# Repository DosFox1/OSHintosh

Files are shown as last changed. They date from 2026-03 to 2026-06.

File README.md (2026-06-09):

# OSHintosh
OSHintosh - an open source hardware Diskless 68000 Macintosh with a Bootable ROM Disk, using absolutely no hardware from Apple!

OSHintosh Complete

OSHintosh operating

OSHintosh running

# DISCLAIMER
The initial VDEV1 board required a large amount of bodges to become operational, these are as follows:

1) Added missing track between pin 1 of the 74ls161s, and pin 8 of the 74ls04 inverter
2) 1x missing 47R resistor TSEN2 from pin 11 of the TSG and ASG to ground
3) 4x missing 2k2 pull up resistors on address lines A9, A10, A11, A12
4) 2x missing 3k3 pull up resistors on !AS and !VIAIRQ
5) pin 4 of IC43 should be connected to -12v, not GND
6) pin 12 of IC18 should be connected to track VA11, not track VA12
7) pin 8 of IC43 should be connected to +12v, not 5V
8) errors on silkscreen for R68, R69, R70 and R71 (Schematic and BOM correct, silkscreen incorrect)
9) errors on silkscreen for R40 and R43 (Schematic and BOM correct, silkscreen incorrect)

VDEV2 has been completed and uploaded. This version should fix all problems with the VDEV1 board, but has not been tested. 

OSHintosh VDEV1 Bodges

# Renders of the VDEV2 Board

OSHintosh Top High Res
OSHintosh Bottom High Res

# So, what is it?
In a nutshell, the OSHintosh is a Macintosh 512Ke Logic Board - but with the exception that it boots from a disk baked into the ROM, power it provided by an ATX power supply, there is an integrated Pico Scan Converter, as well as a SCHWIM to replace the IWM.
The ROM disk is based off the excellent original (ROMinator)[https://www.bigmessowires.com/mac-rom-inator/], and the OSHintosh also has the option to access further files from a LocalTalk server. 

There is no SCSI, No Floppy Drive or any other Mass Storage - it is effectively a Diskless Workstation!
It could be considered to be the spiritual sucessor to the Macintosh XO (also known as the Macintosh Classic!)

The board has also been designed in only two layers, which reduces the cost of the board even further.
JLCPCB suggest that five boards will cost £30 - so only £6 per board. Your mileage may vary. 
41256 RAM was chosen, as it at least avoids the issue of trying to source 30 pin RAM sockets - which are weirdly expensive now. 
It also makes the entire thing a DIP THT Macintosh!

This makes it the first Macintosh designed on a two layer PCB since the "SCC Word Wide" Prototype from 1982!
The board is more or less ATX shaped, but I didn't place the mounting holes to be ATX compliant. Sorry!

This is intended to fit somewhere between the excellent ITX Plus by Max1zzz and the equally excellent PicoMac by evansm7.  
I say this as the RAM is limited to 512K and there is no mass storage, but it does have "real" Localtalk ports to communicate with an AppleTalk network - as well as sound!

# Programmer Requirements:
A Ti866 or similar programmer is recommended. 
In total there are nine programmable ICs that need to be programmed. These are:
1) 6 x 16V8 GALs
2) 2 x 39F040 EEPROMs
3) 1 x ATTINY85 (RTC)

# Hard (ish) to Source Components:
Please Note that the following ICs may be difficult to source:
1) 15.6672mhz oscillator (ebay may have some, if not, custom oscillators can be ordered)
2) Zilog Z8530 SCC
3) 6522 VIA (Demik has noted that the W65C22N6TPG should be a suitable VIA, that's still being made!)
4) 41256 DRAM (x16!)

Please also note this assumes that you have access to either original Macintosh Peripherals, or will add your own adapters!
The OSHintosh uses the original quadrature 9 pin mouse, as well as the original RJ Keyboard. 

# GAL JED Files:
The GALs were sourced from the PLD archive:
https://wiki.pldarchive.co.uk/index.php?title=Macintosh_128k/512k/Plus
For completeness, they have been included here under "OSHintosh GALs". 

Programming can be completed under minipro with:
```
minipro -p GAL16V8* -w (GAL)16V8.jed
```

Equations will be uploaded... eventually.

# Programming the Attiny85 with Minipro 

The ATTINY85 RTC firmware as developed by pgreenland (https://github.com/pgreenland/attinyrtc) can be programmed with a Ti866 under Minipro:
The following erases the ATTINY85:
```
minipro -p ATTINY85 -E
```
Then, the fuses as defined by the file attiny_RTC.fuses is flashed
```
minipro -p ATTINY85 -c config -w attiny_RTC.fuses -e
```
Finally, the firmware is flashed to the ATTINY:
```
minipro -p ATTINY85 -e -c code -f ihex -w ATtinyRTC.hex
```

# Producing new Rominator Disks with a Minipro 

Normally, the ROMinator is designed to be programmed using the BMOW flasher tool onboard the macintosh.
However, this assumes we already have a method of adding mass storage to the Macintosh, which the OSHintosh lacks. 
(https://www.bigmessowires.com/mac-rom-inator/)

As it transpires, the ROMinator just literally tacks an 885K .DSK image onto the end of the modified ROM.
Therefore, the best way to produce a modded ROM is to use mini vmac (or any other suitable emulator!) to modify a copy of the dsk image 
"rominator-disk.dsk" with the desired files and programs
. I would suggest just deleting any unwanted files rather than erasing the disk, as I feel it might break something if it is erased. 
Once content with the resulting disk, the "raw" rominator binary (basically the rominator rom without the disk image) and the new disk should be concatenated together. 

On a Unix machine, this can be done with cat:
```
cat ROMINATOR_RAW.bin oshintosh_disk.dsk > OSHINTOSH_COMBINED.bin
```

In this example, I am using my oshintosh_disk.dsk to create OSHINTOSH_COMBINED.bin.

The next step is to split the comnbined .bin file into two high and low images for the OSHintosh. 
To generate the HIGH ROM:
```
srec_cat -o HIGH.bin -binary OSHINTOSH_COMBINED.bin -binary -split 2 0
```

To generate the LOW ROM:
```
srec_cat -o LOW.bin -binary OSHINTOSH_COMBINED.bin -binary -split 2 1
```

Finally, the two resulting images can then be flashed to the EEPROMs:
```
minipro -p SST39SF040 -w OSHINTOSH_LOW.bin 
```
```
minipro -p SST39SF040 -w OSHINTOSH_HIGH.bin
```

If successful, the OSHintosh should "ping" rather than the usual chime, and when "R" is pressed, the OSHintosh should boot from the ROM.

# Note regarding AppleShare, Chooser and the OSHintosh Serial Ports

If you are wishing to use appleshare to run programs on the OSHintosh, it is best that you use the OSHintosh Disk.dsk files as a starting point. 

This is as the variant of chooser on this startup disk has been recovered from the Macintosh Classic ROM Disk.

Normally, Chooser does not start up on a locked disk. However, the variant of chooser that is found on the Macintosh Classic ROM Disk does work on locked startup disks!

As such, start with the system file as found in OSHintosh Disk.dsk, or OSHintosh Disk 6.0.8.dsk

Additionally, the printer port/Appleshare is connector CN3 (middle connector), and the Modem connector is CN2 (leftmost connector). 

AppleShare on the OSHintosh

# Acknowledgements:
Many thanks to:
AlextheCat,
Bitsavers,
Bolle,
Daniel Kottke,
Demik,
GuruThree, 
HKZ,
Mattmos,
Max1zzz,
Pgreenland,
The PLD Archive,

and many others!

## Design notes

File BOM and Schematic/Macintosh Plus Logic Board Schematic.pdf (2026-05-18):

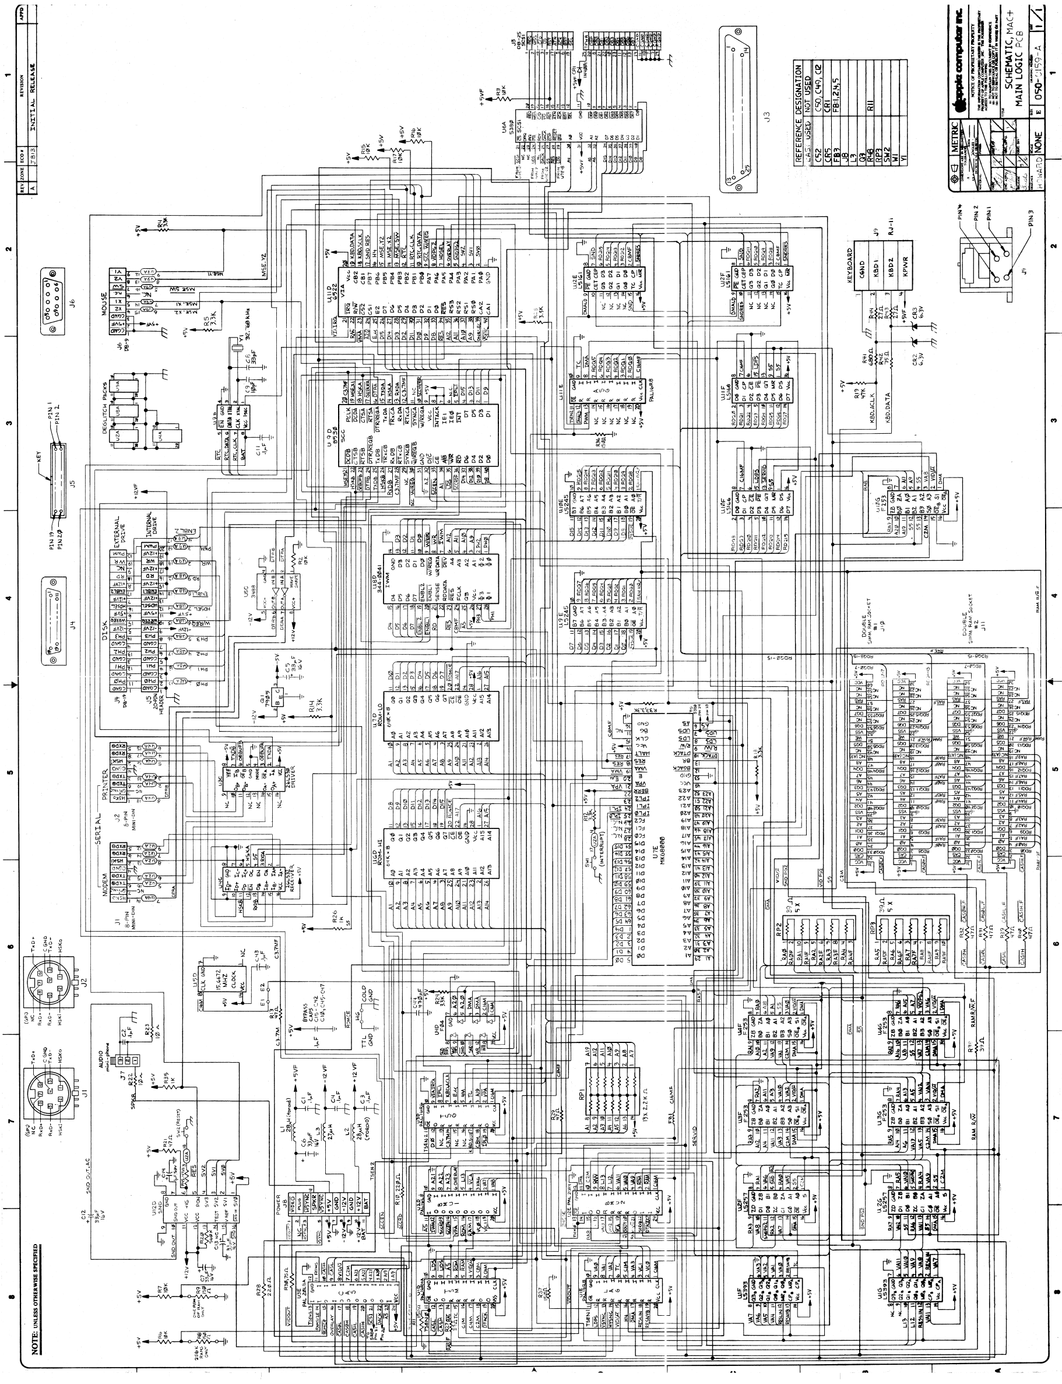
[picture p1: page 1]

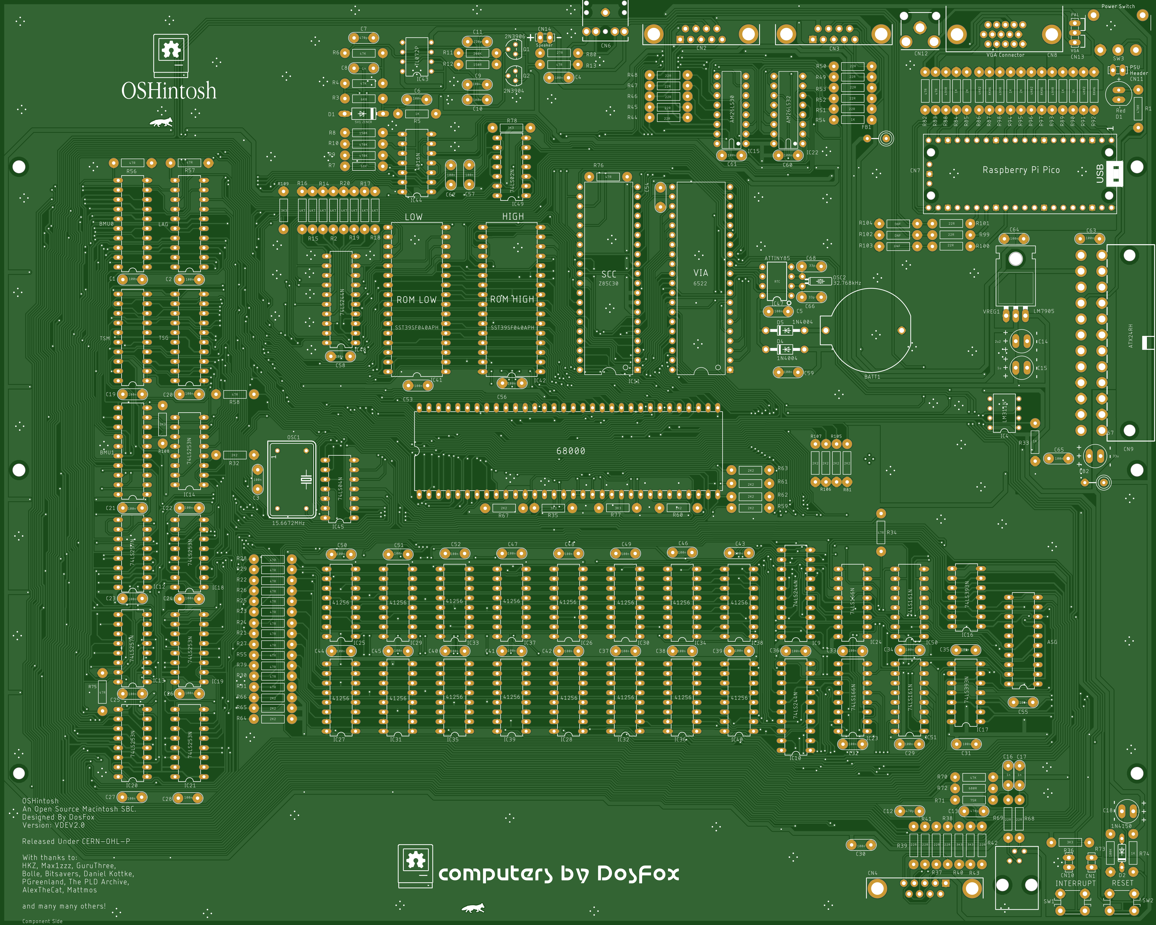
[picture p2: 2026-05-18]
Renders/OSHintosh Top High Res.png

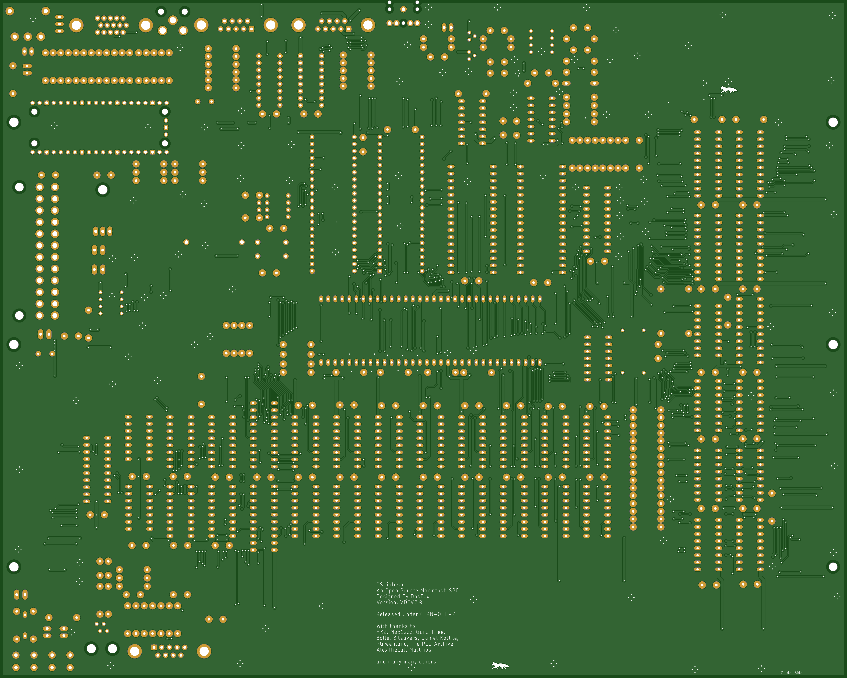
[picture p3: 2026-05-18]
Renders/OSHintosh Bottom High Res.png

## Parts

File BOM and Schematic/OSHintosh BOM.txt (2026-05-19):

Partlist

Exported from OSHintosh v23.sch at 20/Mar/26 10:36

EAGLE Version 9.7.0 Copyright (c) 1988-2026 Autodesk, Inc.

Assembly variant: 

Part     Value                Device                       Package                      Library                 Sheet

BATT1                         BATTERY-20MM_PTH             BATTCOM_20MM_PTH             SparkFun-Batteries      1
C1       100n 50V             100N_TH_CAP                  CAP_5.08MM_PITCH             Capacitors TH           1
C2       100n 50V             100N_TH_CAP                  CAP_5.08MM_PITCH             Capacitors TH           1
C3       100n 50V             100N_TH_CAP                  CAP_5.08MM_PITCH             Capacitors TH           1
C4       100n 50V             100N_TH_CAP                  CAP_5.08MM_PITCH             Capacitors TH           1
C5       100n 50V             100N_TH_CAP                  CAP_5.08MM_PITCH             Capacitors TH           1
C6       100n 50V             100N_TH_CAP                  CAP_5.08MM_PITCH             Capacitors TH           1
C7       470p 50V             470P_TH_CAP                  CAP_5.08MM_PITCH             Capacitors TH           1
C8       1n 50V               1N_TH_CAP                    CAP_5.08MM_PITCH             Capacitors TH           1
C9       100n 50V             100N_TH_CAP                  CAP_5.08MM_PITCH             Capacitors TH           1
C10      100n 50V             100N_TH_CAP                  CAP_5.08MM_PITCH             Capacitors TH           1
C11      220p 50V             220P_TH_CAP                  CAP_5.08MM_PITCH             Capacitors TH           1
C12      470p 50V             470P_TH_CAP                  CAP_5.08MM_PITCH             Capacitors TH           1
C13      470p 50V             470P_TH_CAP                  CAP_5.08MM_PITCH             Capacitors TH           1
C14      2u2 50V              2U2_TH_ELEC_CAPVERTICAL      CAP_ELECTROLYTIC             Capacitors TH           1
C15      1u 50V               1U_TH_ELEC_CAPVERTICAL       CAP_ELECTROLYTIC             Capacitors TH           1
C16      1n 50V               1N_TH_CAP                    CAP_5.08MM_PITCH             Capacitors TH           1
C17      1n 50V               1N_TH_CAP                    CAP_5.08MM_PITCH             Capacitors TH           1
C18      4u7 50V              4U7_TH_ELEC_CAPVERTICAL      CAP_ELECTROLYTIC             Capacitors TH           1
C19      100n 50V             100N_TH_CAP                  CAP_5.08MM_PITCH             Capacitors TH           1
C20      100n 50V             100N_TH_CAP                  CAP_5.08MM_PITCH             Capacitors TH           1
C21      100n 50V             100N_TH_CAP                  CAP_5.08MM_PITCH             Capacitors TH           1
C22      100n 50V             100N_TH_CAP                  CAP_5.08MM_PITCH             Capacitors TH           1
C23      100n 50V             100N_TH_CAP                  CAP_5.08MM_PITCH             Capacitors TH           1
C24      100n 50V             100N_TH_CAP                  CAP_5.08MM_PITCH             Capacitors TH           1
C25      100n 50V             100N_TH_CAP                  CAP_5.08MM_PITCH             Capacitors TH           1
C26      100n 50V             100N_TH_CAP                  CAP_5.08MM_PITCH             Capacitors TH           1
C27      100n 50V             100N_TH_CAP                  CAP_5.08MM_PITCH             Capacitors TH           1
C28      100n 50V             100N_TH_CAP                  CAP_5.08MM_PITCH             Capacitors TH           1
C29      100n 50V             100N_TH_CAP                  CAP_5.08MM_PITCH             Capacitors TH           1
C30      100n 50V             100N_TH_CAP                  CAP_5.08MM_PITCH             Capacitors TH           1
C31      100n 50V             100N_TH_CAP                  CAP_5.08MM_PITCH             Capacitors TH           1
C32      100n 50V             100N_TH_CAP                  CAP_5.08MM_PITCH             Capacitors TH           1
C33      100n 50V             100N_TH_CAP                  CAP_5.08MM_PITCH             Capacitors TH           1
C34      100n 50V             100N_TH_CAP                  CAP_5.08MM_PITCH             Capacitors TH           1
C35      100n 50V             100N_TH_CAP                  CAP_5.08MM_PITCH             Capacitors TH           1
C36      100n 50V             100N_TH_CAP                  CAP_5.08MM_PITCH             Capacitors TH           1
C37      100n 50V             100N_TH_CAP                  CAP_5.08MM_PITCH             Capacitors TH           1
C38      100n 50V             100N_TH_CAP                  CAP_5.08MM_PITCH             Capacitors TH           1
C39      100n 50V             100N_TH_CAP                  CAP_5.08MM_PITCH             Capacitors TH           1
C40      100n 50V             100N_TH_CAP                  CAP_5.08MM_PITCH             Capacitors TH           1
C41      100n 50V             100N_TH_CAP                  CAP_5.08MM_PITCH             Capacitors TH           1
C42      100n 50V             100N_TH_CAP                  CAP_5.08MM_PITCH             Capacitors TH           1
C43      100n 50V             100N_TH_CAP                  CAP_5.08MM_PITCH             Capacitors TH           1
C44      100n 50V             100N_TH_CAP                  CAP_5.08MM_PITCH             Capacitors TH           1
C45      100n 50V             100N_TH_CAP                  CAP_5.08MM_PITCH             Capacitors TH           1
C46      100n 50V             100N_TH_CAP                  CAP_5.08MM_PITCH             Capacitors TH           1
C47      100n 50V             100N_TH_CAP                  CAP_5.08MM_PITCH             Capacitors TH           1
C48      100n 50V             100N_TH_CAP                  CAP_5.08MM_PITCH             Capacitors TH           1
C49      100n 50V             100N_TH_CAP                  CAP_5.08MM_PITCH             Capacitors TH           1
C50      100n 50V             100N_TH_CAP                  CAP_5.08MM_PITCH             Capacitors TH           1
C51      100n 50V             100N_TH_CAP                  CAP_5.08MM_PITCH             Capacitors TH           1
C52      100n 50V             100N_TH_CAP                  CAP_5.08MM_PITCH             Capacitors TH           1
C53      100n 50V             100N_TH_CAP                  CAP_5.08MM_PITCH             Capacitors TH           1
C54      100n 50V             100N_TH_CAP                  CAP_5.08MM_PITCH             Capacitors TH           1
C55      100n 50V             100N_TH_CAP                  CAP_5.08MM_PITCH             Capacitors TH           1
C56      100n 50V             100N_TH_CAP                  CAP_5.08MM_PITCH             Capacitors TH           1
C57      100n 50V             100N_TH_CAP                  CAP_5.08MM_PITCH             Capacitors TH           1
C58      100n 50V             100N_TH_CAP                  CAP_5.08MM_PITCH             Capacitors TH           1
C59      100n 50V             100N_TH_CAP                  CAP_5.08MM_PITCH             Capacitors TH           1
C60      100n 50V             100N_TH_CAP                  CAP_5.08MM_PITCH             Capacitors TH           1
C61      100n 50V             100N_TH_CAP                  CAP_5.08MM_PITCH             Capacitors TH           1
C62      100n 50V             100N_TH_CAP                  CAP_5.08MM_PITCH             Capacitors TH           1
C63      100n 50V             100N_TH_CAP                  CAP_5.08MM_PITCH             Capacitors TH           1
C64      100n 50V             100N_TH_CAP                  CAP_5.08MM_PITCH             Capacitors TH           1
C65      100n 50V             100N_TH_CAP                  CAP_5.08MM_PITCH             Capacitors TH           1
C66      33p                  33P_TH_CAP                   CAP_5.08MM_PITCH             Capacitors TH           1
C67      33u 16V              33U_TH_ELEC_CAPVERTICAL      CAP_ELECTROLYTIC             Capacitors TH           1
C68      33p                  33P_TH_CAP                   CAP_5.08MM_PITCH             Capacitors TH           1
CN1      2way                 PIN_HEADER_2W_VERT_TH        2W_2.54MM_PITCH_VERT_TH      Connectors              1
CN2                           DB9FEMALE                    DB9                          SparkFun-Connectors     1
CN3                           DB9FEMALE                    DB9                          SparkFun-Connectors     1
CN4                           DB9FEMALE                    DB9                          SparkFun-Connectors     1
CN5      XRJK-S-01-6-4-0-9M2  XRJK-S-01-6-4-0-9M2          XRJK-S-01-6-4-0-9M2          con-xmultiple           1
CN6      AUDIO_JACK_3.5MM_PTH AUDIO_JACK_3.5MM_PTH         AUDIO-JACK                   SparkFun-Connectors     1
CN7      V06-1x20-SV-GF-1     PICO_BOARD                   PICO_SOCKET                  uProcessor              1
CN8      DB15                 DB15                         DB15                         SparkFun-Retired        1
CN9      ATX24RH              ATX24RH                      ATX24_RIGHT_ANGLE            SparkFun-Connectors     1
CN10     2way                 PIN_HEADER_2W_VERT_TH        2W_2.54MM_PITCH_VERT_TH      Connectors              1
CN11     2way                 PIN_HEADER_2W_VERT_TH        2W_2.54MM_PITCH_VERT_TH      Connectors              1
CN12     RCA                  RCA                          RCA                          SparkFun-Connectors     1
CN13     V06-1x3-SV-GF-1      PIN_HEADER_3W_VERT_FEMALE_TH 3W_2.54MM_PITCH_VERT_TH      Connectors              1
CN14     2way                 PIN_HEADER_2W_VERT_TH        2W_2.54MM_PITCH_VERT_TH      Connectors              1
D1       5V1 Zener            ZENER-DIODEF126-10           F126Z10                      diode                   1
D2       1N4150               1N4148DO35-7                 DO35-7                       diode                   1
D3       Red                  5MM_LED_RED                  5MM_TH_VERT_STANDARD         Optoelectronics         1
D4       1N4004               1N4004                       DO41-10                      adafruit                1
D5       1N4004               1N4004                       DO41-10                      adafruit                1
FB1      FB                   FB                           FB                           adafruit                1
FB2      FB                   FB                           FB                           adafruit                1
IC1      68000                MC68000P                     DIL64                        micro-mc68000           1
IC2      TSM                  16V8                         DIL20                        pal                     1
IC3      LAG                  16V8                         DIL20                        pal                     1
IC4      LM311N               LM311N                       DIL08                        linear                  1
IC5      TSG                  16V8                         DIL20                        pal                     1
IC6      ASG                  16V8                         DIL20                        pal                     1
IC7      BMU0                 16V8                         DIL20                        pal                     1
IC8      BMU1                 16L8                         DIL20                        pal                     1
IC9      74LS244N             74LS244N                     DIL20                        74xx-eu                 1
IC10     74LS244N             74LS244N                     DIL20                        74xx-eu                 1
IC11     Z85C30               Z85C30                       DIP40                        ICs                     1
IC12     74LS257N             74LS257N                     DIL16                        74xx-eu                 1
IC13     74LS257N             74LS257N                     DIL16                        74xx-eu                 1
IC14     74LS253N             74LS253N                     DIL16                        74xx-eu                 1
IC15     AM26LS30             AM26LS30                     DIP16                        ICs                     1
IC16     74LS393N             74LS393N                     DIL14                        74xx-eu                 1
IC17     74LS393N             74LS393N                     DIL14                        74xx-eu                 1
IC18     74LS253N             74LS253N                     DIL16                        74xx-eu                 1
IC19     74LS253N             74LS253N                     DIL16                        74xx-eu                 1
IC20     74LS253N             74LS253N                     DIL16                        74xx-eu                 1
IC21     74LS253N             74LS253N                     DIL16                        74xx-eu                 1
IC22     AM26LS32             AM26LS32                     DIP16                        ICs                     1
IC23     74LS166N             74LS166N                     DIL16                        74xx-eu                 1
IC24     74LS166N             74LS166N                     DIL16                        74xx-eu                 1
IC25     RAM                  41256C/D                     DIL16                        memory-nec              1
IC26     RAM                  41256C/D                     DIL16                        memory-nec              1
IC27     RAM                  41256C/D                     DIL16                        memory-nec              1
IC28     RAM                  41256C/D                     DIL16                        memory-nec              1
IC29     RAM                  41256C/D                     DIL16                        memory-nec              1
IC30     RAM                  41256C/D                     DIL16                        memory-nec              1
IC31     RAM                  41256C/D                     DIL16                        memory-nec              1
IC32     RAM                  41256C/D                     DIL16                        memory-nec              1
IC33     RAM                  41256C/D                     DIL16                        memory-nec              1
IC34     RAM                  41256C/D                     DIL16                        memory-nec              1
IC35     RAM                  41256C/D                     DIL16                        memory-nec              1
IC36     RAM                  41256C/D                     DIL16                        memory-nec              1
IC37     RAM                  41256C/D                     DIL16                        memory-nec              1
IC38     RAM                  41256C/D                     DIL16                        memory-nec              1
IC39     RAM                  41256C/D                     DIL16                        memory-nec              1
IC40     RAM                  41256C/D                     DIL16                        memory-nec              1
IC41     SST39SF040APH        SST39SF040APH                DIL32                        memory-sst              1
IC42     SST39SF040APH        SST39SF040APH                DIL32                        memory-sst              1
IC43     TL072P               TL072P                       DIL08                        linear                  1
IC44     4016N                4016N                        DIL14                        40xx                    1
IC45     74LS04N              74LS04N                      DIL14                        74xx-eu                 1
IC46     6522                 G65SC22P                     DIP-40                       65XXX                   1
IC47     ATTINY85             ATTINY45TINY85-20-DIP        DIP08_MCU                    SparkFun-Retired        1
IC48     74LS244N             74LS244N                     DIL20                        74xx-eu                 1
IC49     74LS02N              74LS02N                      DIL14                        74xx-us                 1
IC50     74LS161N             74LS161N                     DIL16                        74ttl-din               1
IC51     74LS161N             74LS161N                     DIL16                        74ttl-din               1
OSC1     15.6672MHz           XO-14                        DIL14S                       crystal                 1
OSC2     32.768kHz            CRYSTAL-32.768KHZPTH-2X6     CRYSTAL-PTH-2X6-CYL          SparkFun-Clocks         1
Q1       2N3906               2N3906                       TO92                         transistor-pnp          1
Q2       2N3904               2N3904                       TO92D                        transistor-small-signal 1
R1       470R                 470R_TH_RESISTOR             RESISTORTHRUHOLE             Resistors TH            1
R2       4k7                  4K7_TH_RESISTOR              RESISTORTHRUHOLE             Resistors TH            1
R3       6k8                  6K8_TH_RESISTOR              RESISTORTHRUHOLE             Resistors TH            1
R4       47k                  47K_TH_RESISTOR              RESISTORTHRUHOLE             Resistors TH            1
R5       1k                   1K_TH_RESISTOR               RESISTORTHRUHOLE             Resistors TH            1
R6       47k                  47K_TH_RESISTOR              RESISTORTHRUHOLE             Resistors TH            1
R7       68k                  68K_TH_RESISTOR              RESISTORTHRUHOLE             Resistors TH            1
R8       150k                 150K_TH_RESISTOR             RESISTORTHRUHOLE             Resistors TH            1
R9       470k                 470K_TH_RESISTOR             RESISTORTHRUHOLE             Resistors TH            1
R10      470k                 470K_TH_RESISTOR             RESISTORTHRUHOLE             Resistors TH            1
R11      200k                 100K_TH_RESISTOR             RESISTORTHRUHOLE             Resistors TH            1
R12      150R                 150R_TH_RESISTOR             RESISTORTHRUHOLE             Resistors TH            1
R13      27R                  27R_TH_RESISTOR              RESISTORTHRUHOLE             Resistors TH            1
R14      4k7                  4K7_TH_RESISTOR              RESISTORTHRUHOLE             Resistors TH            1
R15      4k7                  4K7_TH_RESISTOR              RESISTORTHRUHOLE             Resistors TH            1
R16      4k7                  4K7_TH_RESISTOR              RESISTORTHRUHOLE             Resistors TH            1
R17      4k7                  4K7_TH_RESISTOR              RESISTORTHRUHOLE             Resistors TH            1
R18      4k7                  4K7_TH_RESISTOR              RESISTORTHRUHOLE             Resistors TH            1
R19      4k7                  4K7_TH_RESISTOR              RESISTORTHRUHOLE             Resistors TH            1
R20      4k7                  4K7_TH_RESISTOR              RESISTORTHRUHOLE             Resistors TH            1
R21      47R                  47R_TH_RESISTOR              RESISTORTHRUHOLE             Resistors TH            1
R22      47R                  47R_TH_RESISTOR              RESISTORTHRUHOLE             Resistors TH            1
R23      47R                  47R_TH_RESISTOR              RESISTORTHRUHOLE             Resistors TH            1
R24      47R                  47R_TH_RESISTOR              RESISTORTHRUHOLE             Resistors TH            1
R25      47R                  47R_TH_RESISTOR              RESISTORTHRUHOLE             Resistors TH            1
R26      47R                  47R_TH_RESISTOR              RESISTORTHRUHOLE             Resistors TH            1
R27      47R                  47R_TH_RESISTOR              RESISTORTHRUHOLE             Resistors TH            1
R28      47R                  47R_TH_RESISTOR              RESISTORTHRUHOLE             Resistors TH            1
R29      47R                  47R_TH_RESISTOR              RESISTORTHRUHOLE             Resistors TH            1
R30      47R                  47R_TH_RESISTOR              RESISTORTHRUHOLE             Resistors TH            1
R31      47R                  47R_TH_RESISTOR              RESISTORTHRUHOLE             Resistors TH            1
R32      2k2                  2K2_TH_RESISTOR              RESISTORTHRUHOLE             Resistors TH            1
R33      1k                   1K_TH_RESISTOR               RESISTORTHRUHOLE             Resistors TH            1
R34      47R                  47R_TH_RESISTOR              RESISTORTHRUHOLE             Resistors TH            1
R35      3k3                  3K3_TH_RESISTOR              RESISTORTHRUHOLE             Resistors TH            1
R36      3k3                  3K3_TH_RESISTOR              RESISTORTHRUHOLE             Resistors TH            1
R37      22R                  22R_TH_RESISTOR              RESISTORTHRUHOLE             Resistors TH            1
R38      22R                  22R_TH_RESISTOR              RESISTORTHRUHOLE             Resistors TH            1
R39      22R                  22R_TH_RESISTOR              RESISTORTHRUHOLE             Resistors TH            1
R40      3k3                  3K3_TH_RESISTOR              RESISTORTHRUHOLE             Resistors TH            1
R41      22R                  22R_TH_RESISTOR              RESISTORTHRUHOLE             Resistors TH            1
R42      22R                  22R_TH_RESISTOR              RESISTORTHRUHOLE             Resistors TH            1
R43      3k3                  3K3_TH_RESISTOR              RESISTORTHRUHOLE             Resistors TH            1
R44      22R                  22R_TH_RESISTOR              RESISTORTHRUHOLE             Resistors TH            1
R45      22R                  22R_TH_RESISTOR              RESISTORTHRUHOLE             Resistors TH            1
R46      22R                  22R_TH_RESISTOR              RESISTORTHRUHOLE             Resistors TH            1
R47      22R                  22R_TH_RESISTOR              RESISTORTHRUHOLE             Resistors TH            1
R48      22R                  22R_TH_RESISTOR              RESISTORTHRUHOLE             Resistors TH            1
R49      22R                  22R_TH_RESISTOR              RESISTORTHRUHOLE             Resistors TH            1
R50      22R                  22R_TH_RESISTOR              RESISTORTHRUHOLE             Resistors TH            1
R51      22R                  22R_TH_RESISTOR              RESISTORTHRUHOLE             Resistors TH            1
R52      22R                  22R_TH_RESISTOR              RESISTORTHRUHOLE             Resistors TH            1
R53      22R                  22R_TH_RESISTOR              RESISTORTHRUHOLE             Resistors TH            1
R54      1k                   1K_TH_RESISTOR               RESISTORTHRUHOLE             Resistors TH            1
R55      47R                  47R_TH_RESISTOR              RESISTORTHRUHOLE             Resistors TH            1
R56      47R                  47R_TH_RESISTOR              RESISTORTHRUHOLE             Resistors TH            1
R57      47R                  47R_TH_RESISTOR              RESISTORTHRUHOLE             Resistors TH            1
R58      47R                  47R_TH_RESISTOR              RESISTORTHRUHOLE             Resistors TH            1
R59      2k2                  2K2_TH_RESISTOR              RESISTORTHRUHOLE             Resistors TH            1
R60      2k2                  2K2_TH_RESISTOR              RESISTORTHRUHOLE             Resistors TH            1
R61      2k2                  2K2_TH_RESISTOR              RESISTORTHRUHOLE             Resistors TH            1
R62      2k2                  2K2_TH_RESISTOR              RESISTORTHRUHOLE             Resistors TH            1
R63      2k2                  2K2_TH_RESISTOR              RESISTORTHRUHOLE             Resistors TH            1
R64      2k2                  2K2_TH_RESISTOR              RESISTORTHRUHOLE             Resistors TH            1
R65      2k2                  2K2_TH_RESISTOR              RESISTORTHRUHOLE             Resistors TH            1
R66      2k2                  2K2_TH_RESISTOR              RESISTORTHRUHOLE             Resistors TH            1
R67      2k2                  2K2_TH_RESISTOR              RESISTORTHRUHOLE             Resistors TH            1
R68      22R                  22R_TH_RESISTOR              RESISTORTHRUHOLE             Resistors TH            1
R69      22R                  22R_TH_RESISTOR              RESISTORTHRUHOLE             Resistors TH            1
R70      47k                  47K_TH_RESISTOR              RESISTORTHRUHOLE             Resistors TH            1
R71      680R                 680R_TH_RESISTOR             RESISTORTHRUHOLE             Resistors TH            1
R72      75R                  75R_TH_RESISTOR              RESISTORTHRUHOLE             Resistors TH            1
R73      100k                 100K_TH_RESISTOR             RESISTORTHRUHOLE             Resistors TH            1
R74      1k                   1K_TH_RESISTOR               RESISTORTHRUHOLE             Resistors TH            1
R75      47R                  47R_TH_RESISTOR              RESISTORTHRUHOLE             Resistors TH            1
R76      47R                  47R_TH_RESISTOR              RESISTORTHRUHOLE             Resistors TH            1
R77      3k3                  3K3_TH_RESISTOR              RESISTORTHRUHOLE             Resistors TH            1
R78      3k3                  3K3_TH_RESISTOR              RESISTORTHRUHOLE             Resistors TH            1
R79      47R                  47R_TH_RESISTOR              RESISTORTHRUHOLE             Resistors TH            1
R80      47R                  47R_TH_RESISTOR              RESISTORTHRUHOLE             Resistors TH            1
R81      2k2                  2K2_TH_RESISTOR              RESISTORTHRUHOLE             Resistors TH            1
R82      47R                  47R_TH_RESISTOR              RESISTORTHRUHOLE             Resistors TH            1
R83      47R                  47R_TH_RESISTOR              RESISTORTHRUHOLE             Resistors TH            1
R84      1k                   1K_TH_RESISTOR               RESISTORTHRUHOLE             Resistors TH            1
R85      2k                   2K_TH_RESISTOR               RESISTORTHRUHOLE             Resistors TH            1
R86      4k02                 4K02_TH_RESISTOR             RESISTORTHRUHOLE             Resistors TH            1
R87      8k06                 8K06_TH_RESISTOR             RESISTORTHRUHOLE             Resistors TH            1
R88      499R                 499R_TH_RESISTOR             RESISTORTHRUHOLE             Resistors TH            1
R89      1k                   1K_TH_RESISTOR               RESISTORTHRUHOLE             Resistors TH            1
R90      2k                   2K_TH_RESISTOR               RESISTORTHRUHOLE             Resistors TH            1
R91      4k02                 4K02_TH_RESISTOR             RESISTORTHRUHOLE             Resistors TH            1
R92      8k06                 8K06_TH_RESISTOR             RESISTORTHRUHOLE             Resistors TH            1
R93      499R                 499R_TH_RESISTOR             RESISTORTHRUHOLE             Resistors TH            1
R94      1k                   1K_TH_RESISTOR               RESISTORTHRUHOLE             Resistors TH            1
R95      2k                   2K_TH_RESISTOR               RESISTORTHRUHOLE             Resistors TH            1
R96      4k02                 4K02_TH_RESISTOR             RESISTORTHRUHOLE             Resistors TH            1
R97      8k06                 8K06_TH_RESISTOR             RESISTORTHRUHOLE             Resistors TH            1
R98      499R                 499R_TH_RESISTOR             RESISTORTHRUHOLE             Resistors TH            1
R99      22R                  22R_TH_RESISTOR              RESISTORTHRUHOLE             Resistors TH            1
R100     22R                  22R_TH_RESISTOR              RESISTORTHRUHOLE             Resistors TH            1
R101     22R                  22R_TH_RESISTOR              RESISTORTHRUHOLE             Resistors TH            1
R102     DNF                  22R_TH_RESISTOR              RESISTORTHRUHOLE             Resistors TH            1
R103     DNF                  22R_TH_RESISTOR              RESISTORTHRUHOLE             Resistors TH            1
R104     DNF                  22R_TH_RESISTOR              RESISTORTHRUHOLE             Resistors TH            1
R105     2k2                  2K2_TH_RESISTOR              RESISTORTHRUHOLE             Resistors TH            1
R106     2k2                  2K2_TH_RESISTOR              RESISTORTHRUHOLE             Resistors TH            1
R107     2k2                  2K2_TH_RESISTOR              RESISTORTHRUHOLE             Resistors TH            1
R108     3k3                  3K3_TH_RESISTOR              RESISTORTHRUHOLE             Resistors TH            1
R109     3k3                  3K3_TH_RESISTOR              RESISTORTHRUHOLE             Resistors TH            1
SW1      DTS-61               DIP_TACT_SWITCH_6X6TH        DIP_DTS_6_TACT_SWITCH_6X6_TH Switches                1
SW2      DTS-61               DIP_TACT_SWITCH_6X6TH        DIP_DTS_6_TACT_SWITCH_6X6_TH Switches                1
SW3      SS12D16-GDN5         SS12D16-GDN5                 THRUHOLE90DEGSLIDESW         Switches                1
VREG1    LM7905               7905T                        TO220H                       linear                  1

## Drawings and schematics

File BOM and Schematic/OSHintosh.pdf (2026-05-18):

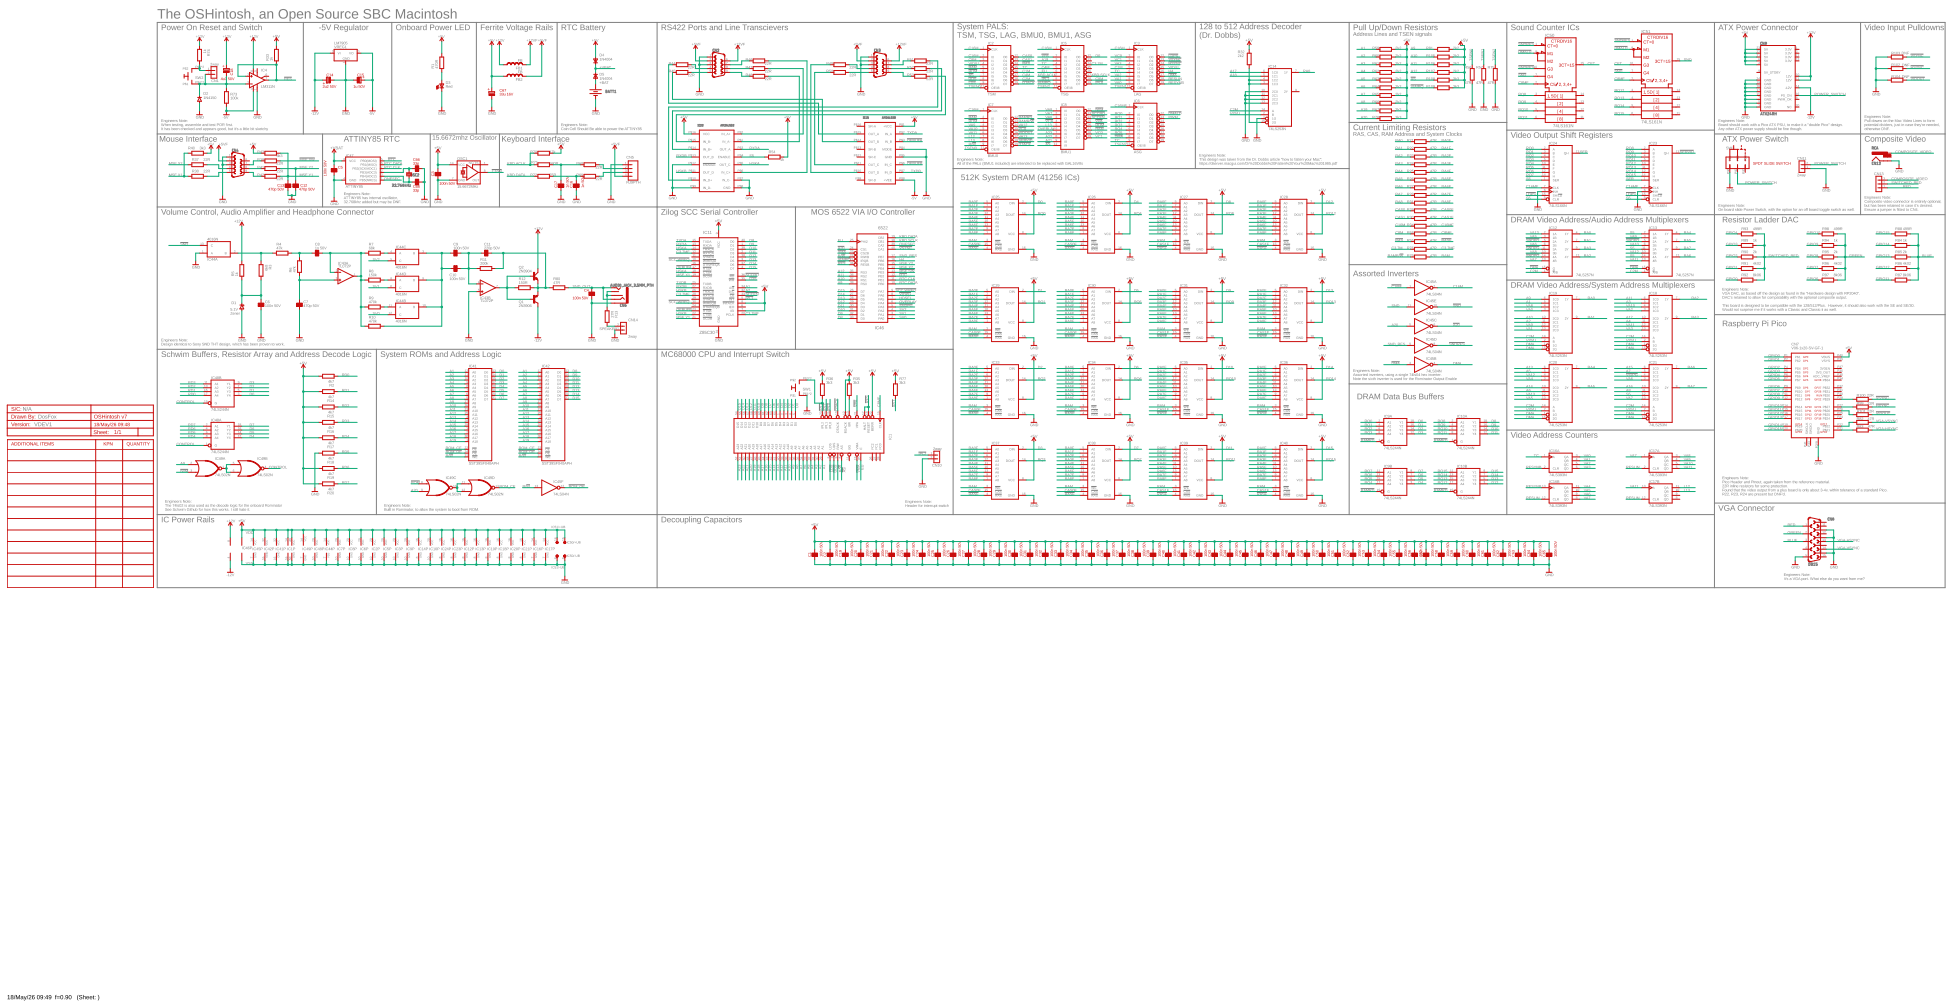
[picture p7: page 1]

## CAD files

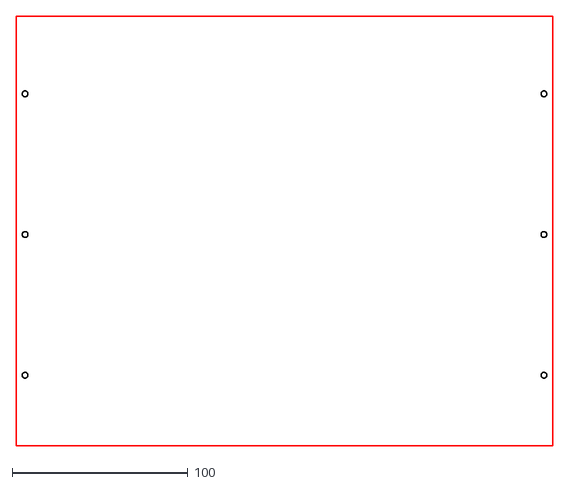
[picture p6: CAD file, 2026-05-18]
SVGs/Board Renders VDEV1/Case Lower Plate.dxf
305.0 x 244.0
